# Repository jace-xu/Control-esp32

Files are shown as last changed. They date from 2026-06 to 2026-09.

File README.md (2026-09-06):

# Vision-Guided Intelligent Logistics Robot

An intelligent logistics robot developed for an engineering innovation course. The system combines omnidirectional movement, computer vision, robotic-arm control, and automated material storage for warehouse handling tasks.

## Key Features

- Raspberry Pi 5 vision system for object and target detection
- ESP32-based motion control and task coordination
- Three-axis robotic arm for automatic picking and placing
- Mecanum-wheel chassis for omnidirectional movement
- Rotary tray capable of storing and managing up to nine objects
- Custom serial protocol for communication between the Raspberry Pi and ESP32

## Tech Stack

**Embedded:** ESP32, Arduino, PlatformIO, C++  
**Vision:** Raspberry Pi 5, Python, OpenCV  
**Mechanical Design:** SolidWorks, 3D printing, laser-cut parts

## Repository Structure

- `Esp32_code/` - ESP32 firmware and control modules
- `Pi5_code/` - Computer vision and serial communication program
- `Structure/` - SolidWorks models and mechanical design files
- `Poster.pdf` - Full project poster

## Robot Photos

<p align="center">
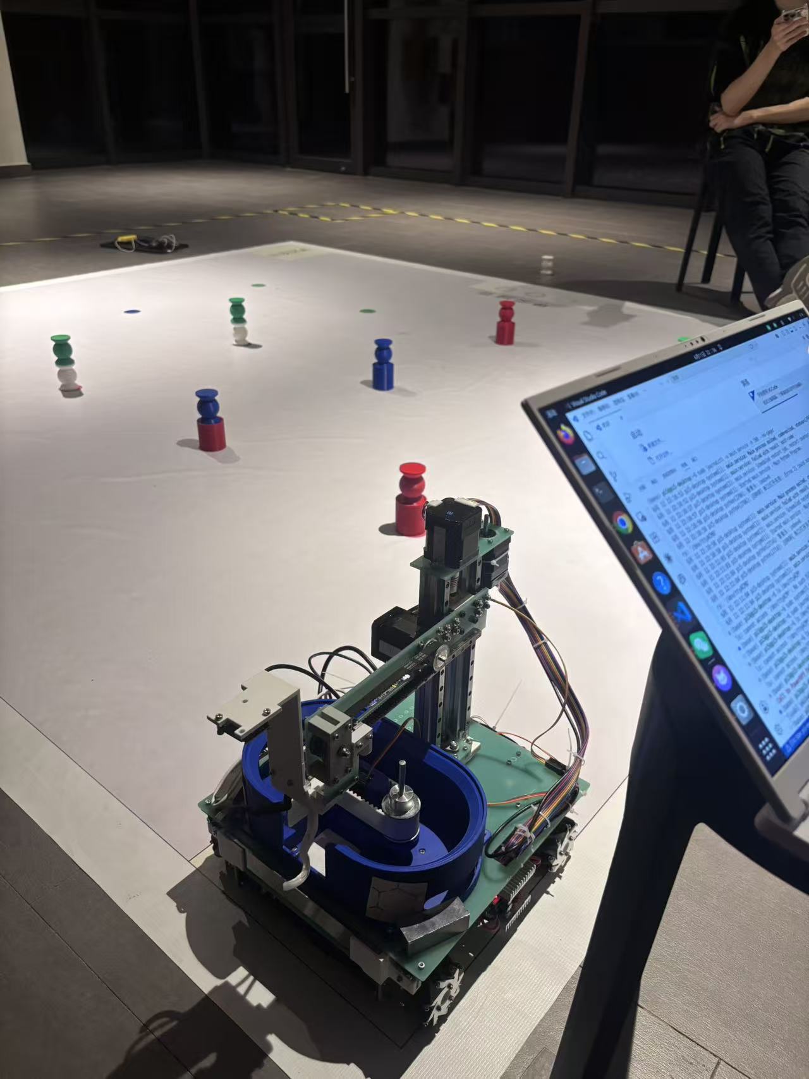
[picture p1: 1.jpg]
Intelligent logistics robot - front view
  
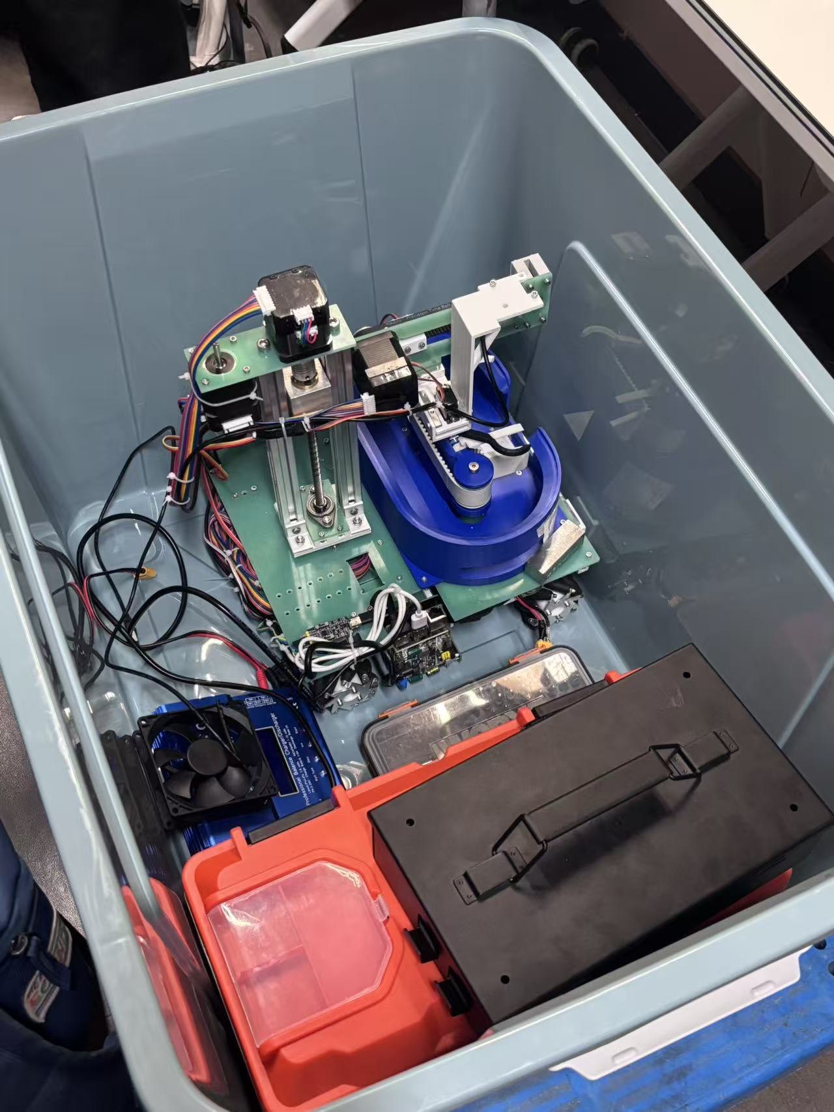
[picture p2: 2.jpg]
Intelligent logistics robot - side view
  
</p>

## Project Poster

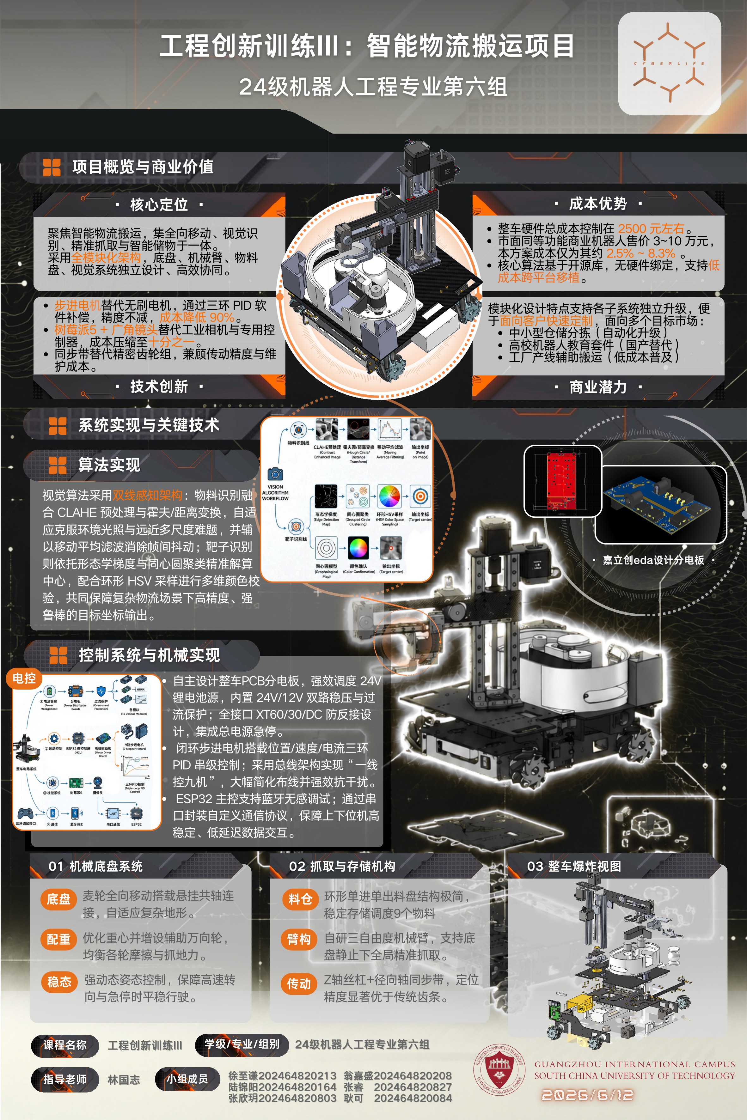
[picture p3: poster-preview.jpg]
Project poster


## License

This project is licensed under the GNU General Public License v3.0. See `LICENSE` for details.

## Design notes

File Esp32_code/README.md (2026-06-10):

# 2026.06.10
# Version 3.2.2

## 工创课-物流小车 ESP32部分的控制代码

## 关于更新和上传：
- [ ! ] 每次上传时请先拉取最新代码，本地合并完成后再上传，以保证你上传的内容最新的
- [ ! ] 尽量不要多人同时改同一个部分

- 每次上传时请先修改项目主目录的 *README.md* （即本文件）
    - 修改日期，日期即为你提交时的日期
    - 主版本号，根据规则修改：
        - 主版本号A.B.C的含义：A-重大更新（大量更改或重写、整体结构更改） | B-普通更新 | C-小更新（修小BUG等等）
        - 更改方式：本位+1、后位清零，按优先级最高的来
        - 例子：原本1.0.2 -> 重大更新，增加了一些功能并改了一些小BUG -> 2.0.0（重大更新优先级最高，A+1，后位都清零）

- 更新日志的规则：
    - 在主目录下的 *version* 文件夹中，创建一个 *最新版本号.md* 的文件
    - 写入更新日期
    - 写入此次更新的具体内容

- 子部分的修改方式：
    - 每个子部分放在对应子文件夹中，包括源代码、必要资源和一份 *README.md*
    - 如果你修改了某个子部分，则需要修改 *README.md* 中的日期，并根据具体的修改，编辑 *README.md* 的内容

- 注意事项：
    - 上传、提交建议直接以版本号命名
    - 不要随意修改别人部分的代码，特别是头文件（有问题叫对应的人改）
    - 如果有新增加的子部分，请按照结构创建
    - *.md* 文件的书写格式尽量符合规范且统一
    - 子部分如果只是修了BUG则只需要修改子 *README.md* 的日期，但是更新日志仍需要说明修复了什么BUG之类的

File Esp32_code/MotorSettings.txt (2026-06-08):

2026.06.04

其他未用到的设置(CAN波特率、通讯返回类型、相电流、电压限制等等，保持默认即可，后续有需要再更改说明)
有的电机是旧的，部分设置没有或者名称不一样，忽略或按照下面的选项修改即可

底盘的四个电机使用Emm固件，上面四个电机采用X固件

[ Hide ]-(隐藏开机LOGO):
    == Enable ==

[ Lock ]-(锁定菜单，防误触):
    == Enable ==

[ Cal ]-(校准电机，点击开始，有选项的话选):
    == Cal_MFL ==

[ MotType ]-(步距角，不要改):
    == 1.8° ==

[ FWType ]-(固件类型，根据要求设定)

[ EmmTurbo ]-(狂暴模式，不要改):
    == Disable ==

[ CtrlMode ]-(控制模式，不要改):
    == CR_VFOC ==

[ P_Pul ]-(脉冲模式):
    == PUL_OFF == (如果不需要脉冲控制)
    == PUL_ENA == (如果需要脉冲控制)

[ P_Serial ]-(通讯端口模式，不要改):
    == UART_FUN ==

[ En ]-(使能模式，不要改):
    == Hold ==

[ Dir ]-(脉冲模式的方向引脚电平模式):
    == CW或CCW == (根据你的需求设置，仅限脉冲模式)

[ MStep ]-(脉冲模式下的细分步数，即原本一步的角度需要走多步，尽量别动):
    == 16 ==

[ MPlyer ]-(脉冲模式下细分插补，不要改):
    == Enable ==

[ AutoSSD ]-(自动息屏，建议关闭):
    == Disable ==

[ UartBaud ]-(通讯波特率，除了CAN):
    == 115200 ==

[ ID_Addr ]-(电机的地址，不能超过16，广播地址是0):
    == 你的电机地址 ==

[ Checksum ]-(通讯校验码，不要改):
    == 0x6B ==

[ Response ]-(电机收到消息后的返回模式，不要开启)
    == None ==

[ S_Vel_IS ]-(速度模式是否缩小十倍输入，要开启):
    == Enable ==

[ S_PosTDP ]-(位置模式是否放大100倍发送，有的电机不支持，所以统一关闭):
    == Disable ==

[ Clog_Pro ]-(堵转保护模式，不要改):
    == AutoZero ==

[ Restore ]-(恢复出厂设置，在电机出现问题时使用)

[ Exit ]-(退出菜单)

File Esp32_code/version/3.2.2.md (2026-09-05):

# 2026.6.10

## 更新内容
- 修复了一些发送指令后未等待的问题
- 更新了一些参数，包括放置时的位置和先后顺序等
- 放置阶段（X 键）重写为**纯手动逐步确认**流程，并按「流程在 TaskCoordinator、其他类只提供动作」
  的架构移入 **TaskCoordinator**，**删除视觉对准与颜色队列**：
    - 流程：按 X 开爪转到出料口（首次自动 `compact()` 压紧）→ 顶料 `dispense()` → 合爪领取 →
      r轴前伸到头 + `notifyPicked()` 送下一块 → 转180°+下降 → **手动 d-pad 瞄准**（左右=角度5，上下=前后7）→
      下降到底 → 开爪放置 → 回升回出料口 → 仓非空续下一块，空则结束。
    - 每一步靠 **X 键上升沿**推进（人确认上一步到位），不做位置轮询自动判定；加步进锁防手快。
    - 手动瞄准用 `setAngleForwardPosition` 打包角度+前后为一条长命令，单次总线事务、满足 ~2ms 间隔。
- **TaskCoordinator** 接管全流程调度：
    - 构造改为注入 *ArmControl* / *ArmSequence* / *TrayControl*；`update` 扩展 d-pad 参数。
    - 每帧推进 `tray->update()`；`isActive()` / `stop()` 并入物料盘忙状态与急停。
    - 阶段1 入仓握手：用 `arm_seq->isActive()` 边沿编排 `prepareStore`（启动）/ `store`（结束，count+1）/
      `tray->stop()`（中止），count 作为阶段2 `dispense()` 出料的前提。
- **ArmSequence** 退化为阶段1 动作提供者：移除 *PlaceSequence* / *ColorQueue* 依赖与记色逻辑，
  保留视觉对准+夹取+收臂；不再处理 X 键。
- **PlaceSequence** 退役（不再被 include/使用，文件保留作历史参考）。
- 修复 **TrayControl** `kTightenTable` 链接错误：补 `static constexpr` 数组的类外定义
  （`dispense`/`compact` 被实际调用后 ODR-use，C++14 需要存储定义）。
- main.cpp：转发 d-pad 给协调器，调整 TaskCoordinator 构造参数。

## 注意事项
- [ ! ] 放置流程所有位置/角度为占位常量，逻辑未实车验证，首跑前需现场校准（撞机/夹空风险）。
- [ ! ] 阶段2 出料要求物料盘 count>0：须先经阶段1 入仓产生数量，否则按 X 提示队空不启动。

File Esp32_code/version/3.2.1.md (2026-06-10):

# 2026.6.10

## 更新内容
- 更新了一些参数
- 优化了一下代码结构

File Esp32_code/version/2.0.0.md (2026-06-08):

# 2026.06.02

## 更新内容：
- 重新书写了 *README.md* 并更改了部分文件命名
- 整理了文件结构，明确了版本修改的控制
- 修改了电机的设置
- 将控制串口、电机控制和底盘控制的底层重新书写，**主程序中部分调用方式需要修改**
    - 在语法上修改了全局单例的获取方式，主程序中需要修改
    - 部分函数修改了名字和参数列表，如果不兼容原版本请修改主程序中的调用方式
    - 增加了多条电机指令同时发送的功能，详情见具体的 *README.md*
    - 取消了每次发送完消息后的固定时间阻塞，改为等待至发送完就返回（具体时长取决于信号长度），但调用时仍需要手动增加间隔（相邻两次发送操作不可连续进行，否则可能会“吞信号”）
    - 增加了多线程保护和线程锁，但注意仍然不可以同时发送，只能保证信号不会串，后来的线程会等待直到正在使用串口的线程调用完后才能继续
    - 暂时未增加电机运动的新功能

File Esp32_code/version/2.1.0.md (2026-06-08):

# 2026.06.04

## 更新内容
- 删除了Motor类，**主程序中的调用方式需更改**
- 更改了BottomControl类的内部实现方法，删除了冗余函数
- 对于ControlSerial类：
    - 修改了部分函数的内部
    - 区分了不同固件的函数，调用时需注意
    - 增加了读取X固件下当前位置的功能

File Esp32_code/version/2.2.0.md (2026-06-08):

# 2026.06.04

## 更新内容：
- 添加了X固件下的速度、绝对位置模式
- 添加了触发同步运动的函数
- 修正了部分错误的注释
- 修改了电机设置

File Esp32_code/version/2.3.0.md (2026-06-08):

# 2026.06.05

## 更新内容
- 测试了ControlSerial部分的代码，并有微小修改：
    - 规范了电机旋转的正方向，统一定为以CW（从电机后侧往轴外看）为正
    - 修改了X固件下位置模式的函数名称

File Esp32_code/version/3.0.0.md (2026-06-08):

# 2026.6.6

## 更新内容
- 整合了电机控制端的代码修改
- 加入预夹取的代码及状态机
- 更新部分放置时的代码
- 修复一些bug

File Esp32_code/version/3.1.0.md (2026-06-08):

# 2026.6.7

## 更新内容
- 新增TrayControl、TaskCoordinator，预留了物料盘的空类，
- 新增VisionStreamHandshake，把视觉串流握手从 ArmSequence 整块搬进新类 VisionStreamHandshake.h
- 新增ColorQueue类，将颜色队列从ArmSequence中分离出来成一个单独的头文件

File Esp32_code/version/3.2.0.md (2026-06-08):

# 2026.6.8

## 更新内容
- 新增PlaceSequence完整实现放置阶段，ArmSequence只保留阶段1(夹取+收臂)。
- 将视觉对准合并进 ArmControl

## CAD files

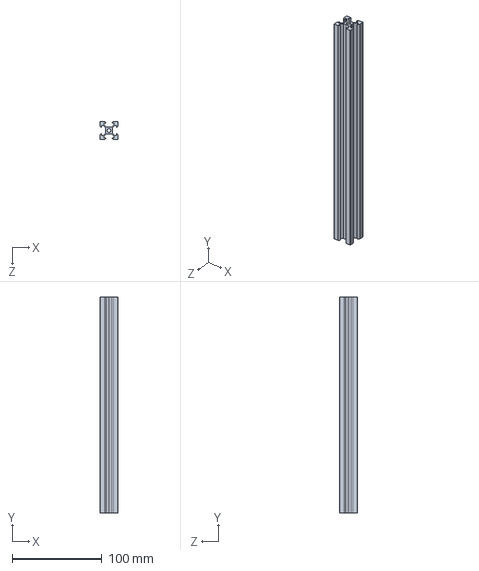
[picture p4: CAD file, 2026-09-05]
Structure/机械臂_v6/型材/欧标2020_240_前.SLDPRT
20.0 x 240.0 x 20.0 mm

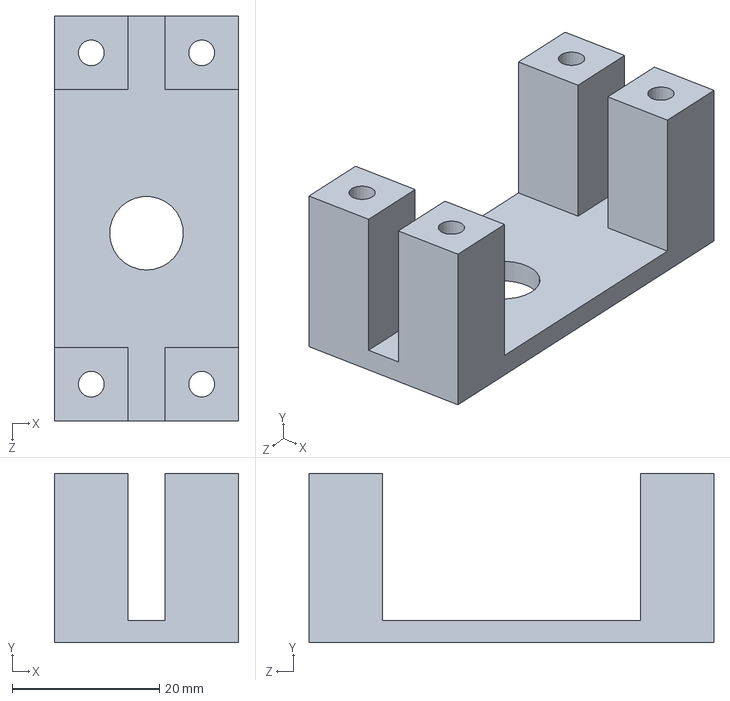
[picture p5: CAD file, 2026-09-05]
Structure/机械臂_v6/打印件/吊臂从动轮外侧固定_打印版.SLDPRT
25.0 x 23.0 x 55.0 mm

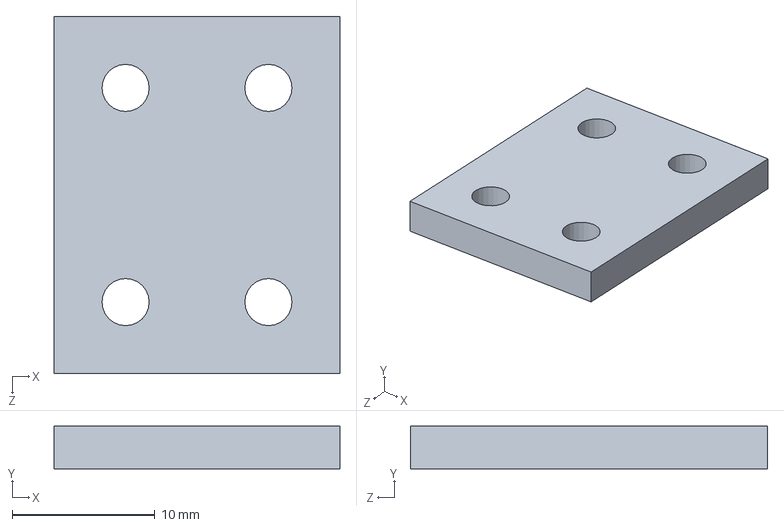
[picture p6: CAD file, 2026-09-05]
Structure/机械臂_v6/板材/六面螺母连接板_3mm.SLDPRT
20.0 x 3.00 x 25.0 mm

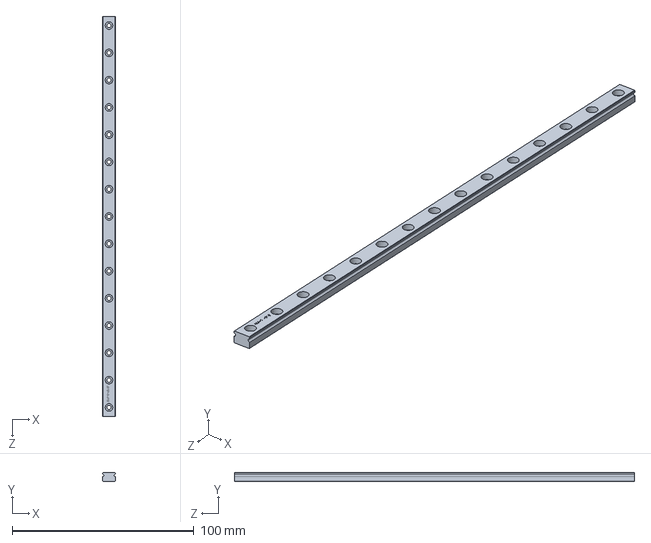
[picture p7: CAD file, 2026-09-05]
Structure/机械臂_v6/购买标准件/线轨MGN7_标件_235.SLDPRT
7.00 x 4.80 x 220.0 mm

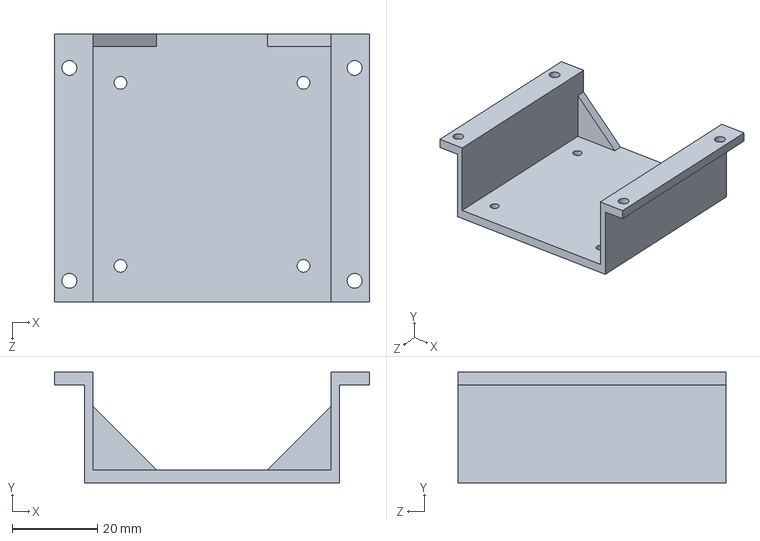
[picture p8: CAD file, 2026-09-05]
Structure/物流小车底盘_v6/底盘/打印件/激光雷达支架.SLDPRT
74.0 x 26.0 x 63.0 mm

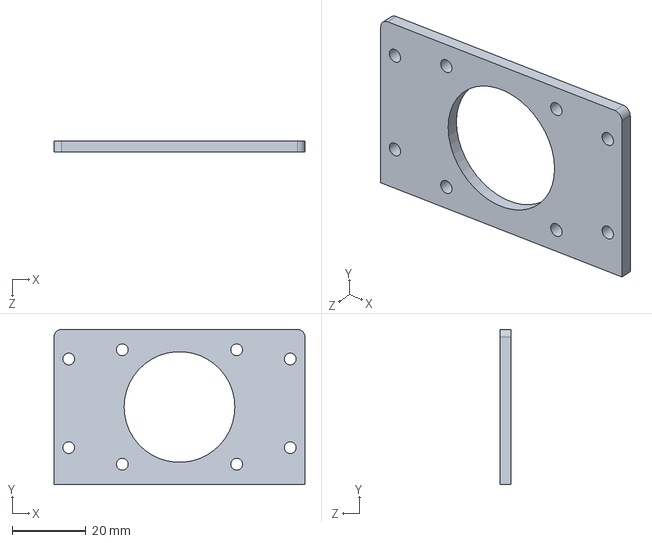
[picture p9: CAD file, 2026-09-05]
Structure/物流小车底盘_v6/底盘/板材/电机连接板_前.SLDPRT
68.0 x 42.0 x 3.00 mm

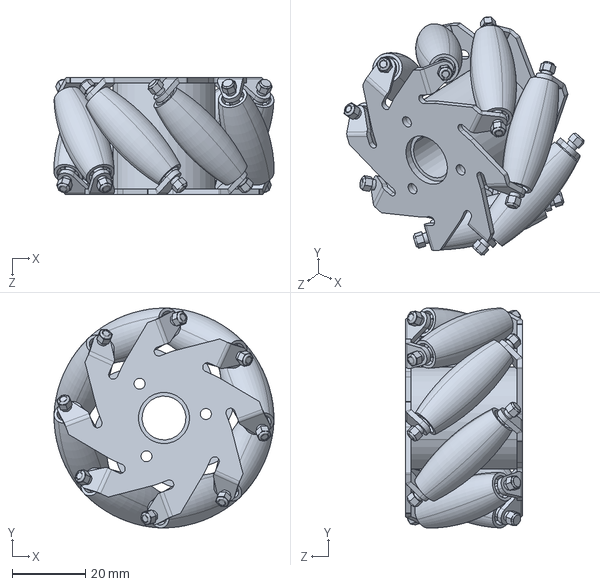
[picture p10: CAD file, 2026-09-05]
Structure/物流小车底盘_v6/底盘/购买件/60mm麦轮_右.SLDPRT
60.1 x 60.1 x 32.0 mm

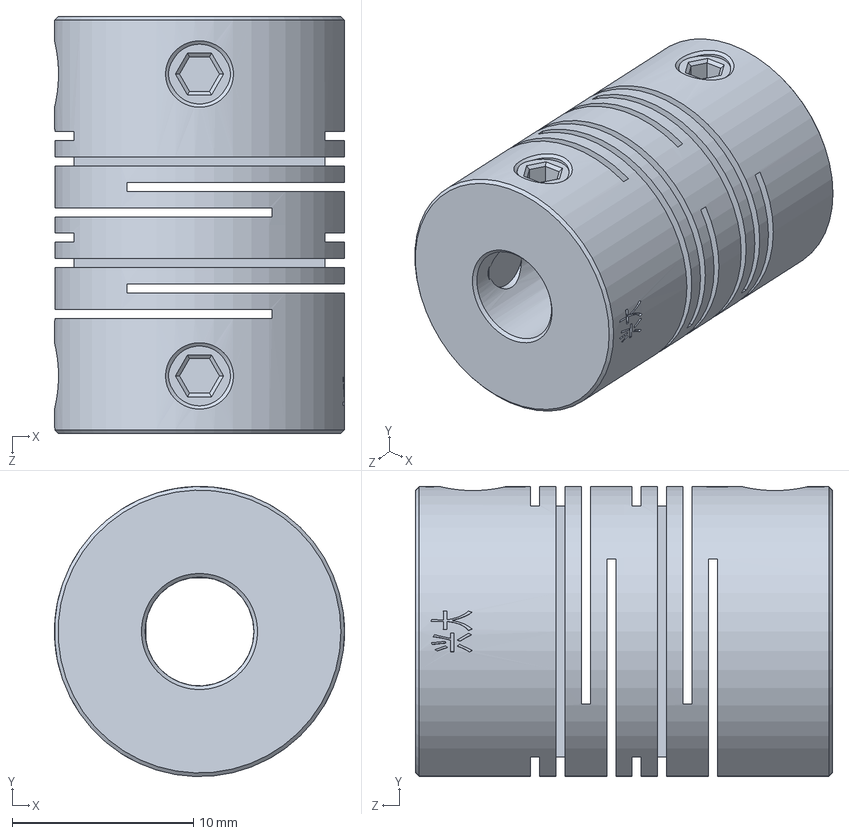
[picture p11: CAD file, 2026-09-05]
Structure/物流小车底盘_v6/标准件/联轴器.SLDPRT
16.0 x 16.0 x 23.0 mm

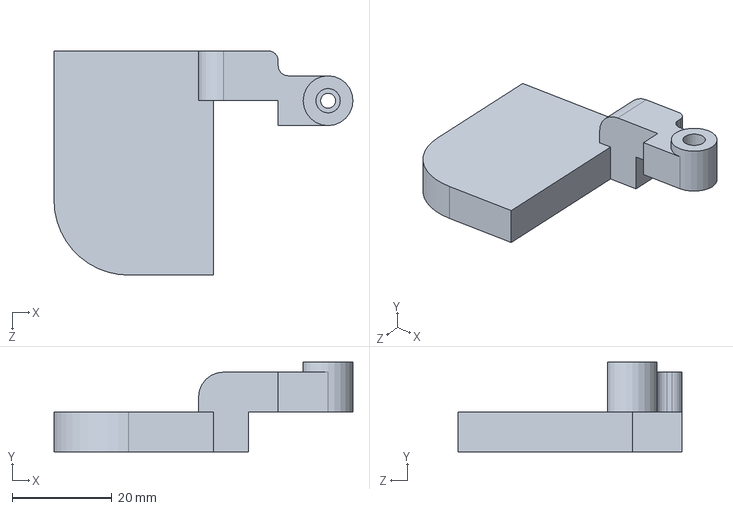
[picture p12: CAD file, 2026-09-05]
Structure/物流小车底盘_v6/物料挡板.SLDPRT
60.0 x 18.0 x 45.0 mm

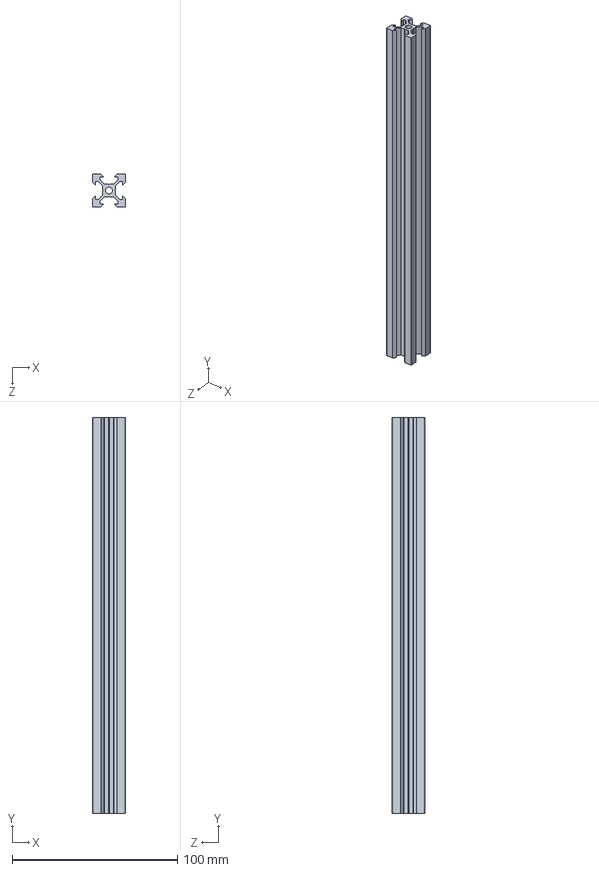
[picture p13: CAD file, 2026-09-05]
Structure/机械臂_v6/型材/欧标2020_240_后.SLDPRT
20.0 x 240.0 x 20.0 mm

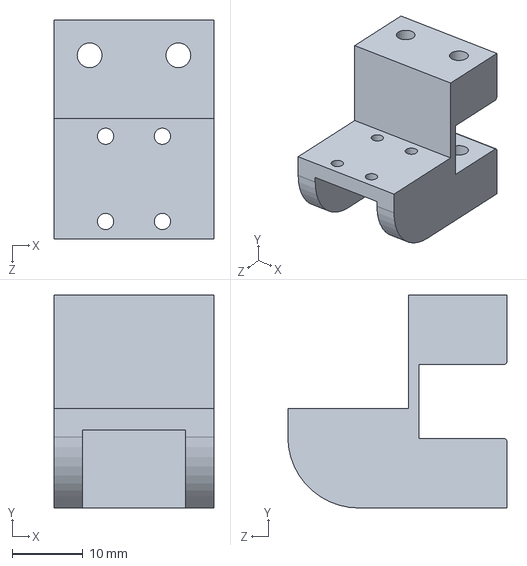
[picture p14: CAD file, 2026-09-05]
Structure/机械臂_v6/打印件/夹爪同步带连接.SLDPRT
22.5 x 30.0 x 30.9 mm

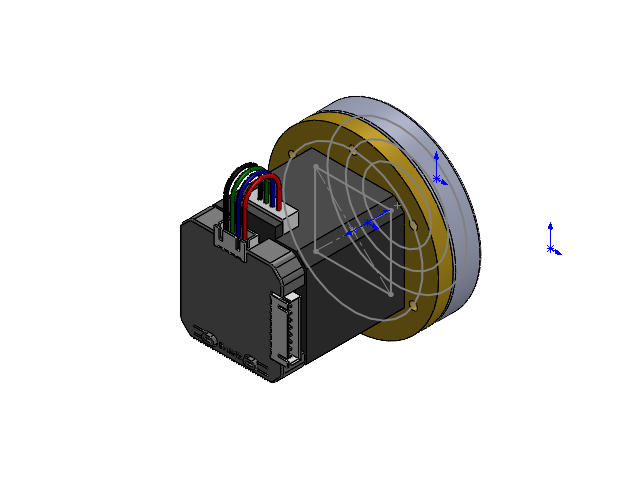
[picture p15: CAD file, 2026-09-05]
Structure/机械臂_v6/.旋转轴装配体.SLDASM
ZDT_X42_L40Motor
底座旋转电机板_5mm
回转轴承

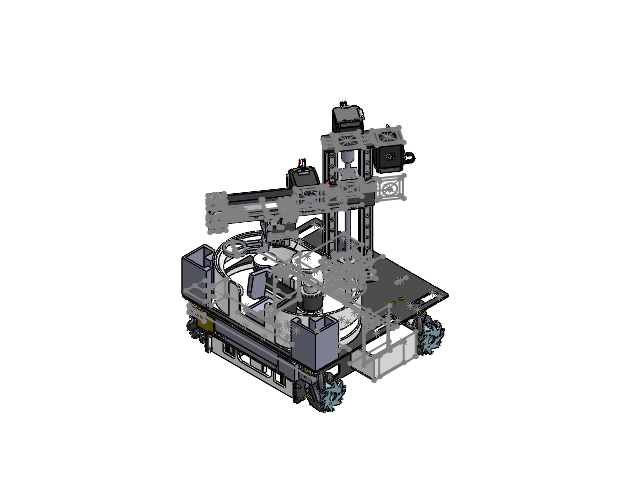
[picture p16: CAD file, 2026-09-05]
Structure/物流小车_v6.SLDASM
同步轮
同步轮惰轮
联轴器
同步带
舵机
小车第一层
板材
齿条连接件
齿条连接件_顶板
齿条50×1
圆柱齿轮18×1
60mm麦轮_右 x 2
60mm麦轮_左 x 2
麦轮联轴器 x 4
电机连接板_前 x 2
42步进电机 x 4
内六角圆柱头螺钉 x 74
六角防松锁紧螺母 x 48
电机连接板_后 x 2
牛眼轮
电机板固定件_牛眼轮架
电机板固定件 x 3
悬挂_半 x 2
M4x8_内六角机牙螺丝 x 8
层连接件 x 4
层连接板_1
M3_16+32_H8_L48 x 2
底板_前
底板_后
铜柱_m2.5_10 x 3
rpi4b
电池仓
纵向支撑板
降压板
esp32
ZDT扩展
ZDT_X42_L40Motor x 5
电机垫片
物料
mg90舵机 x 2
物料挡板
铁块托盘
Mirror铁块托盘
旋转台底板_5mm
2020型材角码 x 4
线轨MGN9_标件_220 x 2
滑块MGN9C_标件_01 x 2
型材顶部板_3mm
丝杆_8_250
丝杆螺母
丝母座
z轴机械臂垫块
欧标2020_240_后
欧标2020_240_前
法兰联轴器_5mm
下部轴承底板
丝杆轴承安装板_3mm
轴承座
轴承垫块
夹爪背板_3mm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

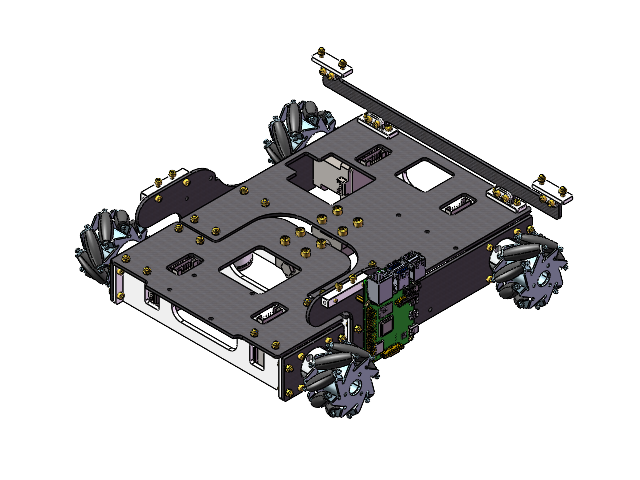
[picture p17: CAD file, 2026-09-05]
Structure/物流小车底盘_v6/底盘/底盘.SLDASM
60mm麦轮_右 x 2
60mm麦轮_左 x 2
麦轮联轴器 x 4
电机连接板_前 x 2
42步进电机 x 4
内六角圆柱头螺钉 x 74
六角防松锁紧螺母 x 50
电机连接板_后 x 2
牛眼轮 x 2
电机板固定件_牛眼轮架
电机板固定件 x 3
悬挂_半 x 2
M4x8_内六角机牙螺丝 x 8
层连接件 x 4
层连接板_1
M3_16+32_H8_L48 x 2
底板_前
底板_后
铜柱_m2.5_10 x 3
rpi4b

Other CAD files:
Structure/机械臂_v6/.吊臂装配体.SLDASM
Structure/机械臂_v6/机械臂装配体.SLDASM
Structure/机械臂_v6/.夹爪装配体.SLDASM
Structure/物流小车底盘_v6/物料盘装配体.SLDASM
Structure/机械臂_v6/打印件/z轴机械臂垫块.SLDPRT
Structure/机械臂_v6/打印件/下部轴承底板.SLDPRT
Structure/机械臂_v6/打印件/夹爪右.SLDPRT
Structure/机械臂_v6/打印件/夹爪左.SLDPRT
Structure/机械臂_v6/打印件/底部电机垫块.SLDPRT
Structure/机械臂_v6/打印件/舵机支架.SLDPRT
Structure/机械臂_v6/打印件/轴承垫块.SLDPRT
Structure/机械臂_v6/板材/丝杆轴承安装板_3mm.SLDPRT
Structure/机械臂_v6/板材/吊臂从动轮外侧固定板_3mm.SLDPRT
Structure/机械臂_v6/板材/型材顶部板_3mm.SLDPRT
Structure/机械臂_v6/板材/夹爪固定板_3mm.SLDPRT
Structure/机械臂_v6/板材/夹爪背板_3mm.SLDPRT
Structure/机械臂_v6/板材/夹爪背板_3mm_修改前.SLDPRT
Structure/机械臂_v6/板材/夹爪连接板_3mm.SLDPRT
Structure/机械臂_v6/板材/底座旋转电机板_5mm.SLDPRT
Structure/机械臂_v6/板材/底座板_3mm.SLDPRT
Structure/机械臂_v6/板材/旋转台底板_5mm.SLDPRT
Structure/机械臂_v6/购买标准件/2020型材角码.SLDPRT
Structure/机械臂_v6/购买标准件/ZDT_X42_L40Motor.SLDPRT
Structure/机械臂_v6/购买标准件/mg90舵机.SLDPRT
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

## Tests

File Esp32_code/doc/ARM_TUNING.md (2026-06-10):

# 机械臂参数整定清单

> 本文列出机械臂相关、**需按实际硬件 / 机械结构 / 现场调试修改**的参数。
> 标 **[必校]** 的不校准会直接导致动作错误或抓取失败；标 **[可调]** 的只影响节奏，不致命。

## 单位约定（重要）

- **视觉误差**（`angleError` / `forwardError`）单位是**像素**（树莓派图像偏差，原始范围 ±3000），不是角度或毫米。相关的死区、收敛阈值、PID 增益都在像素尺度上标定。
- **电机位置**（上下/角度电机）单位是**度**，相对上电零点的绝对角；1 圈 = 360°。
- **方向**由方向因子常量统一控制（见下「方向约定」），不要在多处散改符号。

---

## 1. 接线与通信（`src/main.cpp`）

| 常量 | 占位值 | 等级 | 说明 |
|---|---|---|---|
| `kMotorRxPin` / `kMotorTxPin` | 16 / 17 | [必校] | 电机总线 Serial2 引脚，按实际接线 |
| `kVisionRxPin` / `kVisionTxPin` | 18 / 19 | [必校] | 视觉串口 Serial1 引脚（RX 接树莓派 TX） |
| `kMotorBaudRate` / `kVisionBaudRate` | 115200 | [可调] | 波特率，须与电机驱动器 / 树莓派一致 |
| `kFreshDataGraceMs` | 60ms | [可调] | 手柄数据宽限期，超时停机保护 |

---

## 2. 夹爪舵机（`lib/ArmControl/ArmControl.h`）

普通 PWM 舵机，**无位置反馈**，只能按时间估算闭合/张开耗时。

| 常量 | 占位值 | 等级 | 说明 / 整定建议 |
|---|---|---|---|
| `kGripperPin` | 13 | [必校] | 舵机信号 GPIO，按实际接线；勿与底盘/串口冲突 |
| `kGripperPwmChannel` | 4 | [必校] | LEDC 通道，避开底盘可能占用的 0~3 |
| `kGripperClosedAngle` | 100° | [必校] | 夹紧角度，实测（夹住但不堵转） |
| `kGripperOpenAngle` | 180° | [必校] | 松开角度，实测（完全张开） |
| `kGripperMinPulseUs` / `kGripperMaxPulseUs` | 500 / 2500 | [必校] | 舵机脉宽范围，按舵机手册（多数 0.5~2.5ms 对应 0~180°） |

## 3. 电机地址（`lib/ArmControl/ArmControl.h`）

| 常量 | 值 | 等级 | 说明 |
|---|-----|---|---|
| `kAngleAddr` | 5 | [必校] | 角度电机（旋转对准 / PRE_CATCH 预备摆位） |
| `kVerticalAddr` | 6 | [必校] | 上下电机（升降，位置控制） |
| `kForwardAddr` | 7 | [必校] | 前后电机（进给对准） |

> 三个地址须与电机驱动器实际拨码一致，且与底盘电机（1~4）错开。

---

## 4. 方向约定（`lib/ArmSequence/ArmSequence.h`）

方向只在两个**因子常量**上表达一次，所有圈数/角度常量都乘它。实测方向反了，**只改因子符号**，不要去改各处目标值。

| 常量 | 占位值 | 等级 | 说明 |
|---|---|---|---|
| `kVerticalDirection` | -1.0 | [必校] | 上下电机方向因子：负=下降，正=上升 |
| `kRotationDirection` | -1.0 | [必校] | 角度电机方向因子：正=逆时针，负=顺时针 |

> 底层 `setPosition(addr, deg)` 原样下发角度不取负：正角度→电机一个方向，负角度→反方向。
> 物理上哪个符号是"下降/正转"取决于电机接线与机械结构，须现场实测后定因子符号。

## 5. 位置控制目标与到位（`lib/ArmSequence/ArmSequence.h`）

圈数常量已乘 `kVerticalDirection`；目标绝对角度 = 圈数 × 360°。收臂归位目标为**绝对角（度）**，直接现场标定。

| 常量 | 占位值 | 等级 | 说明 / 整定建议 |
|---|---|---|---|
| `kPreCatchAngleDeg` | 180°×方向 | [必校] | PRE_CATCH 角度电机预备摆位绝对角，实测预备位 |
| `kPreCatchForwardDeg` | 0° | [必校] | PRE_CATCH 前后电机预备摆位绝对角，实测预备位 |
| `kPreDescendRotations` | 0 圈 | [可调] | 对准期先降的圈数 |
| `kDescendTargetRotations` | 5 圈 | [必校] | 阶段1 下降到**夹取位**的圈数，按抓取高度定 |
| `kStowVerticalHomeDeg` | 0° | [必校] | 收臂步骤1 上下电机归位绝对角（0 位最高） |
| `kStowForwardHomeDeg` | 0° | [必校] | 收臂步骤1 前后电机归位绝对角（0 位收回） |
| `kStowAngleDeg` | 0° | [必校] | 收臂步骤2 角度电机归位绝对角 |
| `kStowForwardExtendDeg` | -430° | [必校] | 收臂步骤3 前后电机伸出绝对角（放料位）；方向反了改符号 |
| `kPositionArrivedThreshDeg` | 5° | [可调] | 位置到位判定阈值（电机角度）；太小可能判不到位 |
| `kPositionReadDelayMs`（ArmControl） | 2ms | [可调] | 位置问询后等电机回复的时间；太小读不到位置（返回 false） |

> 阶段1 收臂三步：① 上下→0 同时前后→0 ② 角度→0 ③ 前后伸出到 `kStowForwardExtendDeg` → 松爪放料 →（物料盘逻辑链，待补）。
> 阶段2（放置）目标圈数 `kPlaceDescendRotations` / `kPlaceAscendRotations` 在 `lib/PlaceSequence/PlaceSequence.h`。
> [ ! ] 收臂（STOW）轮询到位依赖角度(5)/上下(6)/前后(7)电机能读位置 → 其驱动器"响应"须开启。

## 6. 视觉伺服 PID（`src/main.cpp` 启动时下发；增益在像素尺度）

| 常量 | 占位值 | 等级 | 说明 |
|---|---|---|---|
| `kArmAngleKp` / `kArmAngleKi` / `kArmAngleKd` | 30 / 0.5 / 5 | [必校] | 角度轴 PID 增益，按对准响应调 |
| `kArmForwardKp` / `kArmForwardKi` / `kArmForwardKd` | 30 / 0.5 / 5 | [必校] | 前后轴 PID 增益 |

ArmControl 内部相关（`setDeadzone`/`setMaxRpm`/`setIntegralLimit` 可改）：

| 成员 | 占位值 | 等级 | 说明 |
|---|---|---|---|
| `deadzone` | 5 像素 | [可调] | 误差死区，\|误差\|<dz 该轴停转 |
| `max_rpm` | 50 rpm | [可调] | 伺服输出限幅 |
| `integral_limit` | 1000 | [可调] | 积分抗饱和限幅 |
| `kVerticalPosSpeed` / `kForwardPosSpeed` / `kAnglePosSpeed` | 800 / 120 / 15 rpm | [可调] | 位置移动速度（按电机区分）。**太慢会撞超时**：移动 N 圈耗时 ≈ N÷(speed/60) 秒，须 < 对应超时（`kDescentTimeoutMs` 等），否则没到位就被超时强停 |

> 对准方向若反：优先在视觉源头（树莓派）或 `updateVisualServo` 入口修正误差符号，
> 不要在输出 rpm 末端取反，也不要用负增益（会掩盖根因）。

## 7. 收敛判定与时序

收敛判定常量在 `lib/ArmControl/ArmControl.h`；时序超时在 `lib/ArmSequence/ArmSequence.h`。

> [ ! ] 当前为**手动确认模式**：`ArmControl::isAligned()` 恒返回 true，收敛计数块已注释。
> 即第二次按 A 即视为"已对准"直接下降，不等自动收敛。下表收敛阈值**当前不生效**，
> 若要恢复自动收敛：取消 `updateAlign` 里收敛计数块注释，并把 `isAligned()` 改回
> `return converge_count >= kConvergeFramesNeeded;`。

| 常量 | 占位值 | 等级 | 说明 |
|---|---|---|---|
| `kConvergeFramesNeeded`（ArmControl） | 10 | [可调] | 连续入阈帧数才算对准（50Hz≈0.2s）。当前不生效 |
| `kConvergeAngleThresh`（ArmControl） | 8 像素 | [必校] | 角度轴收敛判据。当前不生效 |
| `kConvergeForwardThresh`（ArmControl） | 8 像素 | [必校] | 前后轴收敛判据。当前不生效 |
| `kGripSettleMs`（ArmSequence） | 800ms | [可调] | 阶段1 舵机夹紧到位等待（无反馈，按实测闭合耗时，典型 150~400ms） |
| `kPreCatchTimeoutMs`（ArmSequence） | 30s | [可调] | PRE_CATCH 等按 A 的超时 |
| `kPreAlignTimeoutMs`（ArmSequence） | 30s | [可调] | PRE_ALIGN 等确认键的超时 |
| `kDescentTimeoutMs` / `kAscentTimeoutMs`（ArmSequence） | 15s / 12s | [可调] | 下降/收臂归位超时保护（位置反馈失败/卡死兜底） |
| `kStartRetryIntervalMs` / `kStartMaxRetries`（VisionStreamHandshake） | 300ms / 10 | [可调] | 视觉 START 握手重传间隔/次数 |

> 阶段2（放置）的等待 `kGripDelayMs` 等时序在 `lib/PlaceSequence/PlaceSequence.h`。

---

## 上车前必校清单（最小集）

1. 接线引脚（第 1 节）与电机地址（第 3 节）
2. 夹爪夹紧/松开角度（第 2 节）
3. 两个方向因子 `kVerticalDirection` / `kRotationDirection`（第 4 节）—— 先确认下降/正转方向
4. 夹取位圈数 `kDescendTargetRotations`（第 5 节）、放置位圈数（PlaceSequence）
5. 视觉对准 PID 与收敛阈值（第 6、7 节）—— 确认对准方向不反

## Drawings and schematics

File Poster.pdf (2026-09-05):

## 项目概览与商业价值

# 工程创新训练III：智能物流搬运项目

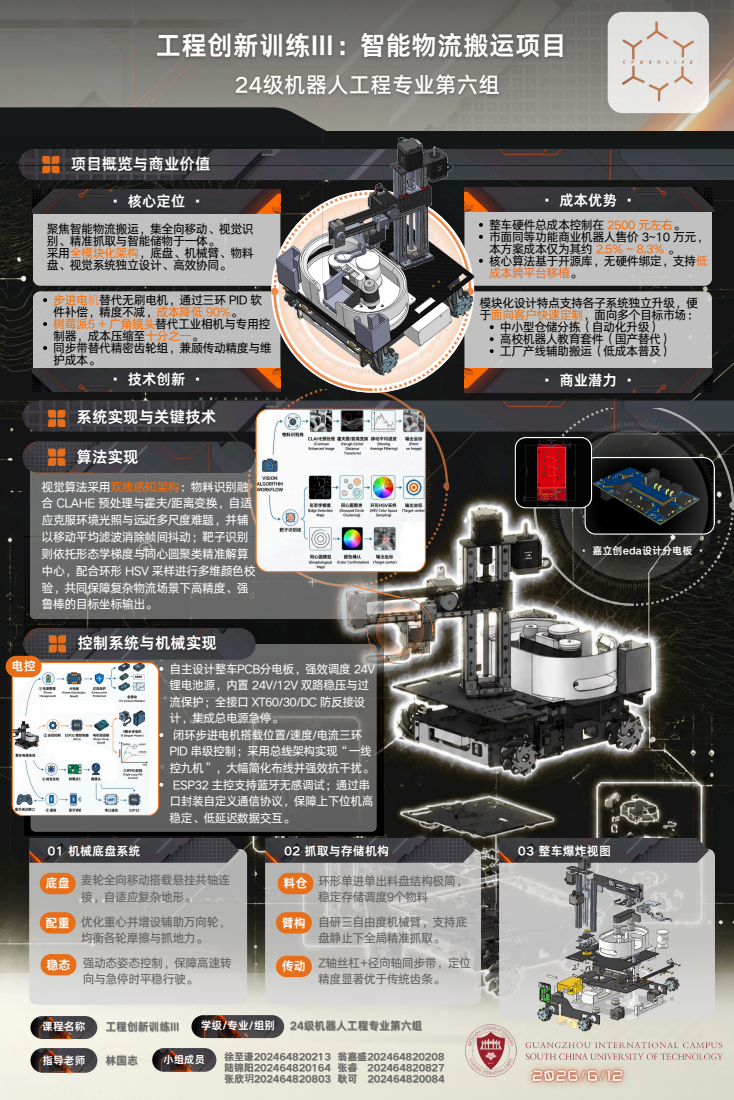
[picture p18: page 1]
02 抓取与存储机构; 一线 ，大幅简化布线并强效抗干扰。; 课程名称; 工程创新训练III; 学级/专业/组别 24级机器人工程专业第六组; 指导老师; 林国志; 小组成员; 算法实现; 控制系统与机械实现; 系统实现与关键技术; 01 机械底盘系统; 底盘 麦轮全向移动搭载悬挂共轴连 接，自适应复杂地形。; 优化重心并增设辅助万向轮， 均衡各轮摩擦与抓地力。; 03 整车爆炸视图; · 技术创新 ·; · 商业潜力 ·; · 核心定位 ·; · 成本优势 ·; 24级机器人工程专业第六组; 模块化设计特点支持各子系统独立升级，便 于面向客户快速定制，面向多个目标市场： 中小型仓储分拣（自动化升级） 高校机器人教育套件（国产替代） 工厂产线辅助搬运（低成本普及）; 强动态姿态控制，保障高速转 向与急停时平稳行驶。; · 嘉立创eda设计分电板 ·; 徐至谦202464820213 翁嘉盛202464820208 陆锦阳202464820164 张睿 202464820827 张欣玥202464820803 耿可 202464820084

整车硬件总成本控制在 2500 元左右。
市面同等功能商业机器人售价 3~10 万元，
本方案成本仅为其约 2.5% ~ 8.3% 。
核心算法基于开源库，无硬件绑定，支持低
成本跨平台移植。

聚焦智能物流搬运，集全向移动、视觉识
别、精准抓取与智能储物于一体。
采用全模块化架构，底盘、机械臂、物料
盘、视觉系统独立设计、高效协同。

步进电机替代无刷电机，通过三环 PID 软
件补偿，精度不减，成本降低 90%。
树莓派5 + 广角镜头替代工业相机与专用控
制器，成本压缩至十分之一
同步带替代精密齿轮组，兼顾传动精度与维
护成本。

视觉算法采用双线感知架构：物料识别融
合 CLAHE 预处理与霍夫/距离变换，自适
应克服环境光照与远近多尺度难题，并辅
以移动平均滤波消除帧间抖动；靶子识别
则依托形态学梯度与同心圆聚类精准解算
中心，配合环形 HSV 采样进行多维颜色校
验，共同保障复杂物流场景下高精度、强
鲁棒的目标坐标输出。

自主设计整车PCB分电板，强效调度 24V
锂电池源，内置 24V/12V 双路稳压与过
流保护；全接口 XT60/30/DC 防反接设
计，集成总电源急停。
闭环步进电机搭载位置/速度/电流三环
PID 串级控制；采用总线架构实现“
控九机”
ESP32 主控支持蓝牙无感调试；通过串
口封装自定义通信协议，保障上下位机高
稳定、低延迟数据交互。

料仓 环形单进单出料盘结构极简，
稳定存储调度9个物料
臂构 自研三自由度机械臂，支持底
盘静止下全局精准抓取。
传动 Z轴丝杠+径向轴同步带，定位
精度显著优于传统齿条。

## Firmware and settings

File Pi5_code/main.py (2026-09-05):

#!/usr/bin/env python3
"""
主控程序 main.py
整合物料识别、靶子识别、串口通信协议

状态机：
  IDLE   → 等待 ESP32 命令
  TASK1  → 物料识别（持续发送物料坐标偏差）
  TASK2  → 靶子识别（持续发送靶子坐标偏差）

串口协议：
  接收：0xBB + cmd + color + 校验
  发送：0xAA + id1 + id2 + data1(int16 LE) + data2(int16 LE) + 校验

用法：
    正常模式: python3 main.py
    无串口调试: python3 main.py --no-serial
"""

import cv2
import numpy as np
import argparse
import sys
import time
import threading
from collections import deque, Counter

# ── 串口 ─────────────────────────────────────────────────────
try:
    import serial
    SERIAL_AVAILABLE = True
except ImportError:
    SERIAL_AVAILABLE = False

SERIAL_PORT = "/dev/ttyACM0"
SERIAL_BAUD = 115200

RX_HEADER = 0xBB
TX_HEADER = 0xAA
CMD_STOP  = 0x00
CMD_TASK1 = 0x01
CMD_TASK2 = 0x02

COLOR_NONE  = 0x00
COLOR_GREEN = 0x01
COLOR_BLUE  = 0x02
COLOR_RED   = 0x03

COLOR_NAME_TO_ID = {"green": 1, "blue": 2, "red": 3, "unknown": 0}
COLOR_ID_TO_NAME = {1: "green", 2: "blue", 3: "red", 0: "unknown"}

# 图像中心
IMG_CX = 320
IMG_CY = 240

# ============================================================
# 串口工具函数
# ============================================================

def open_serial(port=SERIAL_PORT, baud=SERIAL_BAUD, timeout=0.1):
    return serial.Serial(port, baud, timeout=timeout)


def send_error(ser, id1, id2, data1, data2):
    data1 = max(-3000, min(3000, int(data1)))
    data2 = max(-3000, min(3000, int(data2)))
    payload = bytearray()
    payload.append(TX_HEADER)
    payload.append(id1 & 0xFF)
    payload.append(id2 & 0xFF)
    payload += int(data1).to_bytes(2, byteorder="little", signed=True)
    payload += int(data2).to_bytes(2, byteorder="little", signed=True)
    checksum = 0
    for b in payload:
        checksum ^= b
    payload.append(checksum)
    try:
        written = ser.write(bytes(payload))
        return written == len(payload)
    except Exception:
        return False


def receive_command(ser):
    while ser.in_waiting >= 4:
        head = ser.read(1)
        if not head or head[0] != RX_HEADER:
            continue
        rest = ser.read(3)
        if len(rest) < 3:
            return None
        cmd, color, checksum = rest[0], rest[1], rest[2]
        if ((RX_HEADER ^ cmd ^ color) == checksum and
                cmd in (CMD_STOP, CMD_TASK1, CMD_TASK2)):
            return cmd, color
    return None


# ============================================================
# 物料检测（不依赖颜色找圆，再用HSV分类颜色）
# ============================================================

OBJECT_COLOR_RANGES = {
    "red": [
        (np.array([0, 0, 180]), np.array([180, 60, 255])),
    ],
    "blue": [
        (np.array([108, 100, 35]),  np.array([126, 255, 210])),
    ],
    "green": [
        (np.array([48,  120, 45]),  np.array([72,  255, 255])),
    ],
}
OBJECT_COLOR_BGR = {"red": (0,0,220), "blue": (220,80,0),
                    "green": (0,160,0), "unknown": (160,160,160)}

# 移动平均滤波
_obj_cx_hist = deque(maxlen=8)
_obj_cy_hist = deque(maxlen=8)


def _preprocess(frame):
    lab = cv2.cvtColor(frame, cv2.COLOR_BGR2LAB)
    l, a, b = cv2.split(lab)
    clahe = cv2.createCLAHE(clipLimit=3.0, tileGridSize=(8,8))
    l = clahe.apply(l)
    return cv2.cvtColor(cv2.merge([l,a,b]), cv2.COLOR_LAB2BGR)


def _classify_object_color(frame, cx, cy, radius):
    """在检测到的圆形区域内采样HSV判断颜色"""
    hsv  = cv2.cvtColor(frame, cv2.COLOR_BGR2HSV)
    H, W = hsv.shape[:2]
    r    = max(5, int(radius * 0.8))
    x1   = max(0, cx-r); y1 = max(0, cy-r)
    x2   = min(W, cx+r); y2 = min(H, cy+r)
    roi  = hsv[y1:y2, x1:x2]
    if roi.size == 0:
        return "unknown"
    h_roi, w_roi = roi.shape[:2]
    mask = np.zeros((h_roi, w_roi), dtype=np.uint8)
    cv2.circle(mask, (w_roi//2, h_roi//2), r, 255, -1)
    total = int(np.count_nonzero(mask))
    if total == 0:
        return "unknown"
    scores = {}
    for color, ranges in OBJECT_COLOR_RANGES.items():
        cm = np.zeros((h_roi, w_roi), dtype=np.uint8)
        for lo, hi in ranges:
            cm |= cv2.inRange(roi, lo, hi)
        scores[color] = int(np.count_nonzero(cv2.bitwise_and(cm, mask)))
    best = max(scores, key=scores.get)
    return best if scores[best]/total >= 0.08 else "unknown"


def find_object(frame):
    """
    检测物料顶面圆心。
    主方案：霍夫圆。备用：距离变换。
    返回 (cx, cy, radius, color) 或 None。
    """
    H, W     = frame.shape[:2]
    frame_eq = _preprocess(frame)
    gray     = cv2.cvtColor(frame_eq, cv2.COLOR_BGR2GRAY)
    blurred  = cv2.GaussianBlur(gray, (9,9), 2)

    circles = cv2.HoughCircles(
        blurred, cv2.HOUGH_GRADIENT_ALT,
        dp=1.5, minDist=50,
        param1=80, param2=0.70,
        minRadius=30, maxRadius=400)

    cx, cy, r = None, None, None

    if circles is not None:
        result = []
        for ccx, ccy, cr in np.round(circles[0]).astype(int):
            result.append((int(ccx), int(ccy), float(cr)))
        if result:
            max_r   = max(c[2] for c in result)
            cands   = [c for c in result if c[2] >= max_r*0.8]
            best    = max(cands, key=lambda c: np.hypot(
                c[0]-W//2, c[1]-H//2))
            cx, cy, r = best

    if cx is None:
        # 备用：距离变换
        edges = cv2.Canny(blurred, 30, 100)
        inv   = cv2.bitwise_not(edges)
        dist  = cv2.distanceTransform(inv, cv2.DIST_L2, 5)
        _, max_val, _, max_loc = cv2.minMaxLoc(dist)
        cx, cy = max_loc
        r = max(int(max_val * 0.9), min(W,H)//3)

    # 移动平均平滑
    _obj_cx_hist.append(cx)
    _obj_cy_hist.append(cy)
    cx = int(sum(_obj_cx_hist)/len(_obj_cx_hist))
    cy = int(sum(_obj_cy_hist)/len(_obj_cy_hist))

    # 颜色识别
    color = _classify_object_color(frame, cx, cy, r)

    return cx, cy, r, color


# ============================================================
# 靶子检测（v12 SmoothTracker）
# ============================================================

TARGET_COLOR_RANGES = {
    "red": [
        (np.array([0,   40,  0]),  np.array([12,  255, 255])),
        (np.array([154, 40,  0]),  np.array([180, 255, 255])),
    ],
    "blue": [
        (np.array([90,  20,  0]),  np.array([149, 255, 255])),
    ],
    "green": [
        (np.array([43,  25,  0]),  np.array([92,  255, 255])),
    ],
}
TARGET_COLOR_BGR = {
    "red": (0,0,220), "blue": (220,80,0),
    "green": (0,160,0), "unknown": (160,160,160),
}

class SmoothTracker:
    def __init__(self, cx, cy, smooth=15):
        self.history     = [(cx,cy)] * smooth
        self.smooth      = smooth
        self.lost_frames = 0
        self.color       = "unknown"

    def update(self, cx, cy):
        self.history.append((cx,cy))
        if len(self.history) > self.smooth:
            self.history.pop(0)
        self.lost_frames = 0
        return (int(sum(p[0] for p in self.history)/len(self.history)),
                int(sum(p[1] for p in self.history)/len(self.history)))

    def predict(self):
        return (sum(p[0] for p in self.history)/len(self.history),
                sum(p[1] for p in self.history)/len(self.history))


class TargetDetector:
    def __init__(self, min_radius=15, max_radius=300,
                 min_rings=2, cluster_tol=0.45, max_lost=10):
        self.min_radius  = min_radius
        self.max_radius  = max_radius
        self.min_rings   = min_rings
        self.cluster_tol = cluster_tol
        self.max_lost    = max_lost
        self._clahe      = cv2.createCLAHE(clipLimit=3.0, tileGridSize=(8,8))
        self._trackers   = {}
        self._next_id    = 0

    def _preprocess(self, frame):
        lab = cv2.cvtColor(frame, cv2.COLOR_BGR2LAB)
        l, a, b = cv2.split(lab)
        l = self._clahe.apply(l)
        return cv2.cvtColor(cv2.merge([l,a,b]), cv2.COLOR_LAB2BGR)

    def _enhance_edges(self, gray):
        eroded  = cv2.erode(gray, None, iterations=2)
        dilated = cv2.dilate(eroded, np.ones((7,7),np.uint8), iterations=1)
        clahe   = cv2.createCLAHE(clipLimit=5.0, tileGridSize=(8,8))
        clahed  = clahe.apply(dilated)
        k5      = cv2.getStructuringElement(cv2.MORPH_ELLIPSE,(5,5))
        grad    = cv2.morphologyEx(clahed, cv2.MORPH_GRADIENT, k5)
        b1      = cv2.GaussianBlur(grad,(7,7),3)
        enh     = cv2.convertScaleAbs(b1, alpha=4, beta=0)
        b2      = cv2.GaussianBlur(enh,(7,7),3)
        return cv2.adaptiveThreshold(
            b2,255,cv2.ADAPTIVE_THRESH_GAUSSIAN_C,
            cv2.THRESH_BINARY,11,2)

    def _detect_circles(self, enhanced):
        circles = cv2.HoughCircles(
            enhanced, cv2.HOUGH_GRADIENT_ALT,
            dp=1.5, minDist=10,
            param1=80, param2=0.75,
            minRadius=self.min_radius,
            maxRadius=self.max_radius)
        if circles is None:
            return np.empty((0,3), dtype=np.float32)
        return np.round(circles[0]).astype(np.float32)

    def _cluster(self, circles):
        if len(circles)==0: return []
        used  = [False]*len(circles)
        order = np.argsort(-circles[:,2])
        groups= []
        for i in order:
            if used[i]: continue
            cx,cy,cr = circles[i]
            grp = [(cx,cy,cr)]; used[i]=True
            for j in order:
                if used[j]: continue
                cx2,cy2,cr2 = circles[j]
                if np.hypot(cx-cx2,cy-cy2)<max(cr,cr2)*self.cluster_tol:
                    grp.append((cx2,cy2,cr2)); used[j]=True
            if len(grp)<self.min_rings: continue
            ws  = np.array([g[2] for g in grp],dtype=np.float32); ws/=ws.sum()
            mcx = float(np.sum([g[0]*w for g,w in zip(grp,ws)]))
            mcy = float(np.sum([g[1]*w for g,w in zip(grp,ws)]))
            groups.append({"center":(mcx,mcy),
                           "radii":sorted([float(g[2]) for g in grp])})
        return groups

    def _classify_color(self, hsv, cx, cy, r_min, r_max):
        H,W = hsv.shape[:2]
        pad = int(r_max)+2
        x1=max(0,int(cx)-pad); y1=max(0,int(cy)-pad)
        x2=min(W,int(cx)+pad); y2=min(H,int(cy)+pad)
        roi=hsv[y1:y2,x1:x2]
        if roi.size==0: return "unknown"
        h,w=roi.shape[:2]; lx,ly=int(cx)-x1,int(cy)-y1
        mo=np.zeros((h,w),np.uint8); mi=np.zeros((h,w),np.uint8)
        cv2.circle(mo,(lx,ly),int(r_max),255,-1)
        cv2.circle(mi,(lx,ly),max(1,int(r_min*0.8)),255,-1)
        ring=cv2.subtract(mo,mi); total=int(np.count_nonzero(ring))
        if total==0: return "unknown"
        scores={}
        for color,ranges in TARGET_COLOR_RANGES.items():
            cm=np.zeros((h,w),np.uint8)
            for lo,hi in ranges: cm|=cv2.inRange(roi,lo,hi)
            scores[color]=int(np.count_nonzero(cv2.bitwise_and(cm,ring)))
        best=max(scores,key=scores.get)
        return best if scores[best]/total>=0.02 else "unknown"

    def _update_trackers(self, detections):
        MATCH_DIST=80
        preds={tid:tk.predict() for tid,tk in self._trackers.items()}
        for tk in self._trackers.values(): tk.lost_frames+=1
        matched=set(); results=[]
        for det in detections:
            raw_cx,raw_cy=float(det["cx"]),float(det["cy"])
            color,radii=det["color"],det["radii"]
            best_tid=None; best_dist=MATCH_DIST
            for tid,(px,py) in preds.items():
                d=np.hypot(raw_cx-px,raw_cy-py)
                if d<best_dist and tid not in matched:
                    best_dist=d; best_tid=tid
            if best_tid is not None:
                tk=self._trackers[best_tid]
                sx,sy=tk.update(raw_cx,raw_cy)
                if color!="unknown": tk.color=color
                matched.add(best_tid)
            else:
                tk=SmoothTracker(raw_cx,raw_cy); tk.color=color
                tid=self._next_id; self._next_id+=1
                self._trackers[tid]=tk
                sx,sy=tk.update(raw_cx,raw_cy); matched.add(tid)
            results.append({"color":tk.color,"cx":sx,"cy":sy,"radii":radii})
        dead=[t for t,tk in self._trackers.items()
              if tk.lost_frames>self.max_lost]
        for t in dead: del self._trackers[t]
        return results

    def detect(self, frame):
        frame_eq=self._preprocess(frame)
        scale=0.5
        small=cv2.resize(frame_eq,(0,0),fx=scale,fy=scale)
        gray =cv2.cvtColor(small,cv2.COLOR_BGR2GRAY)
        hsv  =cv2.cvtColor(small,cv2.COLOR_BGR2HSV)
        enhanced=self._enhance_edges(gray)
        circles =self._detect_circles(enhanced)
        groups  =self._cluster(circles)
        detections=[]
        for g in groups:
            cx_s,cy_s=g["center"]; radii_s=g["radii"]
            color=self._classify_color(hsv,cx_s,cy_s,radii_s[0],radii_s[-1])
            detections.append({
                "cx":cx_s/scale,"cy":cy_s/scale,
                "color":color,
                "radii":sorted([r/scale for r in radii_s])[:6],
            })
        return self._update_trackers(detections)


# ============================================================
# 主状态机
# ============================================================

STATE_IDLE  = "IDLE"
STATE_TASK1 = "TASK1"
STATE_TASK2 = "TASK2"

def run(no_serial=False, show_debug=True, auto_task1=False, auto_task2=False,
    force_task1=False, force_task2=False):
    # 打开摄像头
    cap = cv2.VideoCapture(0)
    if not cap.isOpened():
        print("[ERROR] 无法打开摄像头"); sys.exit(1)
    W = int(cap.get(cv2.CAP_PROP_FRAME_WIDTH))
    H = int(cap.get(cv2.CAP_PROP_FRAME_HEIGHT))
    print(f"摄像头: {W}x{H}")

    # 打开串口
    ser = None
    if not no_serial:
        if not SERIAL_AVAILABLE:
            print("[ERROR] pyserial未安装，请用 --no-serial 模式")
            sys.exit(1)
        try:
            ser = open_serial()
            print(f"串口: {SERIAL_PORT} @ {SERIAL_BAUD}")
        except Exception as e:
            print(f"[ERROR] 串口打开失败: {e}")
            sys.exit(1)
    else:
        print("[调试] 无串口模式，键盘模拟命令：1=物料 2=靶子(红) q=停止")

    target_detector = TargetDetector()

    if auto_task1 and auto_task2:
        auto_task2 = False
    if force_task1:
        auto_task1 = True
        auto_task2 = False
    if force_task2:
        auto_task2 = True
        auto_task1 = False
    state        = STATE_TASK1 if auto_task1 else (STATE_TASK2 if auto_task2 else STATE_IDLE)
    task2_color  = COLOR_RED if auto_task2 else 0  # ESP32指定的靶子颜色id
    # 靶子颜色确认缓冲：收集3秒投票
    color_buf     = []
    confirm_start = None
    confirmed     = False      # 是否已确认并发送过9
    confirm_done  = False      # 是否已完成首次3s确认流程

    print(f"状态: {state}")

    while True:
        ret, frame = cap.read()
        if not ret:
            print("[WARN] 读帧失败")
            continue

        vis = frame.copy()

        # ── 读串口命令 ────────────────────────────────────
        if ser:
            result = receive_command(ser)
            if result is not None:
                cmd, color = result
                if cmd == CMD_STOP:
                    state = STATE_IDLE
                    color_buf.clear(); confirm_start=None; confirmed=False; confirm_done=False
                    print(f"[串口] STOP → IDLE")
                elif cmd == CMD_TASK1:
                    state = STATE_TASK1
                    _obj_cx_hist.clear(); _obj_cy_hist.clear()
                    print(f"[串口] TASK1 → 物料识别")
                elif cmd == CMD_TASK2:
                    state       = STATE_TASK2
                    task2_color = color
                    color_buf.clear(); confirm_start=time.time()
                    confirmed=False; confirm_done=False
                    print(f"[串口] TASK2 color={COLOR_ID_TO_NAME.get(color,'?')} → 靶子识别")
        else:
            # 键盘模拟
            key = cv2.waitKey(1) & 0xFF
            if key == ord('1'):
                state = STATE_TASK1
                _obj_cx_hist.clear(); _obj_cy_hist.clear()
                print("模拟: TASK1")
            elif key == ord('2'):
                state = STATE_TASK2; task2_color = COLOR_RED
                color_buf.clear(); confirm_start=time.time()
                confirmed=False; confirm_done=False
                print("模拟: TASK2 (红色)")
            elif key == ord('q'):
                state = STATE_IDLE
                print("模拟: STOP")
            elif key == 27:   # ESC退出
                break

        # ── TASK1：物料识别 ───────────────────────────────
        if state == STATE_TASK1:
            cx, cy, r, color = find_object(frame)
            dx = cx - IMG_CX
            dy = cy - IMG_CY
            color_id = COLOR_NAME_TO_ID.get(color, 0)

            # 发送
            if ser:
                send_error(ser, 1, color_id, dx, dy)

            # 可视化
            bgr = OBJECT_COLOR_BGR.get(color, (160,160,160))
            cv2.circle(vis, (cx,cy), int(r), bgr, 2)
            cv2.circle(vis, (cx,cy), 6, bgr, -1)
            cv2.drawMarker(vis,(IMG_CX,IMG_CY),(255,255,255),
                           cv2.MARKER_CROSS,30,2)
            cv2.arrowedLine(vis,(IMG_CX,IMG_CY),(cx,cy),(255,255,0),2)
            cv2.putText(vis,
                        f"TASK1 {color} ({cx},{cy}) dx={dx:+d} dy={dy:+d}",
                        (8,30),cv2.FONT_HERSHEY_SIMPLEX,0.6,bgr,2)
            print(f"[TASK1] {color}(id={color_id}) dx={dx:+d} dy={dy:+d}")

        # ── TASK2：靶子识别 ───────────────────────────────
        elif state == STATE_TASK2:
            if confirm_start is None:
                confirm_start = time.time()
            targets = target_detector.detect(frame)
            target_color_name = COLOR_ID_TO_NAME.get(task2_color, "unknown")

            # 找和ESP32指定颜色一致的靶子
            matched = [t for t in targets
                       if t["color"] == target_color_name]

            cv2.drawMarker(vis,(IMG_CX,IMG_CY),(255,255,255),
                           cv2.MARKER_CROSS,30,2)

            if not confirm_done and targets:
                for t in targets:
                    if t["color"] != "unknown":
                        color_buf.append(t["color"])

            elapsed = time.time() - confirm_start
            if not confirm_done and elapsed >= 3.0:
                if color_buf:
                    vote_color = Counter(color_buf).most_common(1)[0][0]
                    if vote_color == target_color_name:
                        confirmed = True
                        print(f"[TASK2] 确认! {vote_color}")
                    else:
                        print(f"[TASK2] 颜色不一致 vote={vote_color} expected={target_color_name}")
                confirm_done = True

            if matched:
                t   = matched[0]
                cx  = t["cx"]; cy = t["cy"]
                dx  = cx - IMG_CX
                dy  = cy - IMG_CY
                bgr = TARGET_COLOR_BGR.get(t["color"],(160,160,160))
            else:
                cx = cy = dx = dy = 0
                bgr = (160,160,160)

            if confirmed and matched:
                if ser:
                    send_error(ser, 2, 9, dx, dy)
            else:
                if ser:
                    send_error(ser, 2, 0, 0, 0)

            if matched:
                for rv in t["radii"][:6]:
                    cv2.circle(vis,(cx,cy),int(rv),bgr,2)
                cv2.circle(vis,(cx,cy),6,bgr,-1)
                cv2.arrowedLine(vis,(IMG_CX,IMG_CY),(cx,cy),(255,255,0),2)

            if confirmed:
                status = "✓确认"
            elif confirm_done:
                status = "未确认"
            else:
                status = f"投票{elapsed:.1f}s"

            if not matched:
                cv2.putText(vis,
                            f"TASK2 找不到 {target_color_name}",
                            (8,30),cv2.FONT_HERSHEY_SIMPLEX,
                            0.6,(160,160,160),2)
            else:
                cv2.putText(vis,
                            f"TASK2 {t['color']} ({cx},{cy}) "
                            f"dx={dx:+d} dy={dy:+d} [{status}]",
                            (8,30),cv2.FONT_HERSHEY_SIMPLEX,0.6,bgr,2)

        # ── IDLE ─────────────────────────────────────────
        else:
            cv2.putText(vis,"IDLE - 等待命令",
                        (8,30),cv2.FONT_HERSHEY_SIMPLEX,
                        0.7,(200,200,200),2)

        # 状态显示
        cv2.putText(vis, f"state:{state}",
                    (8,H-10),cv2.FONT_HERSHEY_SIMPLEX,
                    0.5,(200,200,200),1)

        if show_debug:
            cv2.imshow("Main (ESC=quit)", vis)
            if not no_serial:
                if cv2.waitKey(1) & 0xFF == 27:
                    break

    cap.release()
    cv2.destroyAllWindows()
    if ser:
        ser.close()


def main():
    parser = argparse.ArgumentParser()
    parser.add_argument("--no-serial",  action="store_true",
                        help="无串口调试模式，键盘模拟命令")
    parser.add_argument("--auto-task1", action="store_true",
                        help="启动后直接进入TASK1（便于无串口测试）")
    parser.add_argument("--auto-task2", action="store_true",
                        help="启动后直接进入TASK2（默认红色靶子，用于无串口测试）")
    parser.add_argument("--force-task1", action="store_true",
                        help="不等ESP32命令，直接进入TASK1并走串口发送")
    parser.add_argument("--force-task2", action="store_true",
                        help="不等ESP32命令，直接进入TASK2并走串口发送")
    parser.add_argument("--no-display", action="store_true",
                        help="不显示画面（无头模式）")
    args = parser.parse_args()
    run(no_serial=args.no_serial,
        show_debug=not args.no_display,
        auto_task1=args.auto_task1,
        auto_task2=args.auto_task2,
        force_task1=args.force_task1,
        force_task2=args.force_task2)


if __name__ == "__main__":
    main()

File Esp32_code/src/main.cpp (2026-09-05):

#include <Arduino.h>
#include <BottomControl.h>
#include <ArmControl.h>
#include <ArmSequence.h>
#include <TrayControl.h>
#include <TaskCoordinator.h>
#include <VisionSerial.h>
#include <GamepadInput.h>

namespace {

// ============================================================================
// 硬件引脚和通信配置
// ============================================================================

constexpr int kMotorBaudRate = 115200;   // 电机控制总线波特率 (Serial2)
constexpr int kMotorRxPin = 16;          // 电机总线 RX (GPIO16)
constexpr int kMotorTxPin = 17;          // 电机总线 TX (GPIO17)
constexpr int kVisionBaudRate = 115200;  // 视觉串口波特率 (Serial1)
constexpr int kVisionRxPin = 18;         // 视觉串口 RX (GPIO18, 接树莓派 TX)
constexpr int kVisionTxPin = 19;         // 视觉串口 TX (GPIO19, 接树莓派 RX)

// ============================================================================
// 安全参数
// ============================================================================

// 手柄数据宽限期: 最后一次收到新数据后, 超过此时间(ms)仍未收到新帧,
// 则自动停止底盘和机械臂, 防止通信中断时执行机构继续运动。
constexpr uint32_t kFreshDataGraceMs = 60;

// ============================================================================
// 全局对象指针 (在 setup() 中初始化)
// ============================================================================

BottomControl* g_bottom_control = nullptr;   // 底盘控制 (地址 1~4: 四个麦克纳姆轮, 单例)
ArmControl* g_arm_control = nullptr;         // 机械臂控制 (地址 5:角度, 6:上下, 7:前后)
VisionSerial* g_vision_serial = nullptr;     // 视觉数据串口 (Serial1, 接收树莓派误差数据)
ArmSequence* g_arm_sequence = nullptr;       // 机械臂任务编排 (视觉伺服 + 上下序列状态机)
TrayControl* g_tray_control = nullptr;       // 物料盘控制 (骨架, 动作待补)
TaskCoordinator* g_task_coordinator = nullptr; // 上层协调器 (机械臂 + 物料盘; 当前透传)

// ============================================================================
// 全局状态标志
// ============================================================================

bool g_is_stopped = true;          // 底盘当前是否已停止
bool g_timeout_reported = false;   // 手柄超时警告是否已经输出过 (避免重复打印)
uint32_t g_last_fresh_input_ms = 0; // 最后一次收到有效手柄数据的时间戳

// ============================================================================
// 安全控制函数
// ============================================================================

/// @brief 停止底盘所有电机 (四个麦克纳姆轮)
void stopChassis() {
    if (g_bottom_control != nullptr) {
        g_bottom_control->stop();
    }
    g_is_stopped = true;
}

/// @brief 停止机械臂所有电机并复位状态机
/// @note 委托给协调器 (机械臂 + 未来物料盘); 协调器未就绪时回退到 ArmSequence
void stopArm() {
    if (g_task_coordinator != nullptr) {
        g_task_coordinator->stop();
    } else if (g_arm_sequence != nullptr) {
        g_arm_sequence->stop();
    }
}

/// @brief 安全停止: 同时停止底盘和机械臂
/// @note 通常在紧急情况或手柄断连/超时时调用
void safetyStopAll() {
    stopChassis();
    stopArm();
}

// ============================================================================
// 底盘控制
// ============================================================================

/// @brief 将手柄解析出的底盘速度命令下发给底盘控制库
/// @param input 手柄输入状态 (包含 vx, vy, wz 三个速度分量)
/// @note vx: 前后速度 mm/s, vy: 左右速度 mm/s, wz: 旋转角速度 rad/s
void applyChassisCommand(const InputState& input) {
    g_bottom_control->motors_control({
        input.chassis.vx_mm_s,
        input.chassis.vy_mm_s,
        input.chassis.wz_rad_s,
    });
    g_is_stopped = false;
}

// ============================================================================
// 机械臂控制
// ============================================================================

/// @brief 将手柄按键与方向键转发给上层任务协调器
/// @param input 手柄输入状态
/// @note  两阶段模式 (放置流程已移到 TaskCoordinator):
///        - A 键(阶段1): 视觉对准 + 夹取 + 收臂, 并由 TC 编排物料盘入仓 (store, count+1)。
///        - X 键(阶段2): 纯手动逐步确认的放置流程 (出料), 每按一次推进一步。
///        - B 键: 中止当前运行。
///        - L1 键(阶段1前置): 空闲时角度电机预备摆位。
///        - d-pad 上下左右: 放置流程手动瞄准 (左右→角度电机, 上下→前后电机)。
///        边沿检测与流程逻辑封装在 TaskCoordinator / ArmSequence。
void applyArmCommand(const InputState& input) {
    g_task_coordinator->update(input.buttons.a, input.buttons.x, input.buttons.b,
                               input.buttons.l1, input.buttons.dpadX, input.buttons.dpadY,
                               input.buttons.y);
}

}  // namespace

// ============================================================================
// Arduino setup() — 上电初始化
// ============================================================================

void setup() {
    // 初始化调试串口 (USB 连接电脑)
    Serial.begin(115200);
    delay(200);
    Serial.println("Chassis and arm control program started");

    // ---- 初始化电机控制串口 (Serial2) ----
    // GPIO16 = RX, GPIO17 = TX
    // 该总线挂载 7 个电机驱动器:
    //   地址 1 ~ 4: 底盘麦克纳姆轮 (左前, 右前, 左后, 右后)
    //   地址 5:     机械臂角度电机
    //   地址 6:     机械臂上下电机
    //   地址 7:     机械臂前后电机
    ControlSerial::get_instance().initialize(kMotorBaudRate, kMotorRxPin, kMotorTxPin);

    // 初始化底盘控制 (地址 1~4, 单例)
    g_bottom_control = &(BottomControl::get_instance());

    // ---- 初始化视觉数据串口 (Serial1) ----
    // GPIO18 = RX (接树莓派 TX), GPIO19 = TX (接树莓派 RX)
    // 协议: 0xAA + ID1(uint8) + ID2(uint8) + 角度误差(int16 LE) + 前后误差(int16 LE), 共 8 字节
    // [ ! ] 须在 ArmControl 之前创建: ArmControl 集成视觉对准, 构造需传入 VisionSerial 指针
    g_vision_serial = new VisionSerial(kVisionBaudRate, kVisionRxPin, kVisionTxPin);

    // 初始化机械臂控制 (地址 5/6/7, 共用同一 Serial2 总线; 集成视觉对准, 依赖 VisionSerial)
    g_arm_control = new ArmControl(g_vision_serial);

    // 初始化机械臂任务编排 (依赖 ArmControl, 须在其之后创建)
    g_arm_sequence = new ArmSequence(g_arm_control);

    // 初始化物料盘控制 (骨架; 与底盘/机械臂共用 Serial2 总线)
    g_tray_control = new TrayControl();

    // 初始化上层协调器 (依赖 ArmControl / ArmSequence / TrayControl, 须在三者之后创建)
    g_task_coordinator = new TaskCoordinator(g_arm_control, g_arm_sequence, g_tray_control);

    // ---- 初始化 Bluepad32 蓝牙手柄输入层 ----
    GamepadInput::begin();

    // ---- 上电安全: 先停止所有执行机构, 避免上电瞬间误动作 ----
    stopChassis();
    stopArm();

    // 机械臂 PID 增益的权威默认值定义在 ArmControl 内 (现场标定值);
    // 如需运行时改, 在此调用 g_arm_control->setAnglePID/setForwardPID 覆盖。

    Serial.println("Initialization complete");
}

// ============================================================================
// Arduino loop() — 主循环 (约 50Hz, 每 20ms 执行一次)
// ============================================================================
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

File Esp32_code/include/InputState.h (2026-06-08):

#pragma once

#include <stdint.h>

struct ChassisCommand {
    float vx_mm_s = 0.0f;
    float vy_mm_s = 0.0f;
    float wz_rad_s = 0.0f;
};

struct StickState {
    int lx = 0;
    int ly = 0;
    int rx = 0;
    int ry = 0;
};

struct TriggerState {
    int left = 0;
    int right = 0;
};

struct ButtonState {
    bool a = false;
    bool b = false;
    bool x = false;
    bool y = false;
    bool l1 = false;
    bool r1 = false;
    bool start = false;
    bool select = false;
    bool thumbL = false;
    bool thumbR = false;
    int dpadX = 0;
    int dpadY = 0;
};

struct ArmCommand {
    float joint1 = 0.0f;
    float joint2 = 0.0f;
    float joint3 = 0.0f;
    float joint4 = 0.0f;
    float gripper = 0.0f;
};

struct InputState {
    bool connected = false;
    bool hasFreshData = false;
    bool timedOut = false;
    uint32_t timestampMs = 0;
    StickState sticks;
    TriggerState triggers;
    ButtonState buttons;
    ChassisCommand chassis;
    ArmCommand arm;
    bool armServoTrigger = false;      // True when visual servo button is held
};

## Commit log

2026-05-30 初始化仓库
2026-05-30 优化了代码结构
2026-06-02 加入pid
2026-06-02 修改文件路径
2026-06-03 包装机械臂抓取函数
2026-06-03 加上误差2
2026-06-08 初始化dev-jace分支，进行物料盘开发
2026-06-09 初版物料仓代码
2026-06-09 基本完成物料盘
2026-06-10 第一版完整流程完成
2026-06-10 实现夹取
2026-06-10 夹取放置全部完成，还差调参
2026-06-10 可用版本+1
2026-06-10 最新可用版本
2026-06-11 最新版本，接下来改时序逻辑，你需要，万一改坏了回退到这一版
2026-06-11 又是最新版可用，现在开始调手动自动混合
2026-06-11 手动模式已解决
2026-06-11 最新版可用
2026-06-11 准备改控制周期
2026-06-11 准备改加一
2026-06-11 准备debug
2026-06-11 保存，准备新建分支精简
2026-09-05 最新的版本，上传了准备
2026-09-05 更改文件结构
2026-09-05 增加机械和海报和算法
    [.吊臂装配体.SLDASM, .夹爪装配体.SLDASM, .旋转轴装配体.SLDASM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]
2026-09-05 增加readme和海报
2026-09-05 修改readme和增加图片
